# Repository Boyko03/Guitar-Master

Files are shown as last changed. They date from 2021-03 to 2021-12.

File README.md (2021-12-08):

# *Guitar Master*
Have you ever dreamed of learning to play the guitar? Guitar Master will help you make your dream come true!

Read this in other languages: [Bulgarian](https://github.com/Boyko03/Guitar-Master/blob/main/README.bg.md)
## How do I download and use the project?

### Necessary parts
[Parts](https://github.com/Boyko03/Guitar-Master/blob/main/Hardware/parts.csv)

### Download instructions

1) Clone the GitHub repository locally
```bash
  git clone https://github.com/Boyko03/Guitar-Master.git
```
Or download it as a [zip](https://github.com/Boyko03/Guitar-Master/archive/refs/heads/main.zip)

### Installation instructions

1) The Software/main directory contains the program that Arduino Uno runs.
2) Load the program into your Arduino

### Instructions for starting the project

1) It is recommended to solder the elements on the boards included in the repository, but the scheme can also be recreated on a Breadboard.
2) When the elements are connected correctly, a "snake" will appear on the fretboard, and a menu will be displayed on the LCD screen, which is controlled by the buttons.
3) Guitar Master can display notes and chords as well as songs.

## Technologies used

* [KiCad](https://kicad.org/) - A Cross Platform and Open Source Electronics Design Automation Suite
* [Arduino](https://www.arduino.cc/) - Arduino is an open source project for the design and production of an electronic platform with easy-to-use free hardware and software,

## Аbout the authors of the project

* **Boyko Georgiev** - *programmer, designer, hardware engineer* - [Boyko03](https://github.com/Boyko03)

## Photos and demonstration
[Electric Schema](https://github.com/Boyko03/Guitar-Master/blob/main/Hardware/guitar.pdf) <br />
[Demo](https://github.com/Boyko03/Guitar-Master/blob/main/Presentation/demo.mp4) <br />
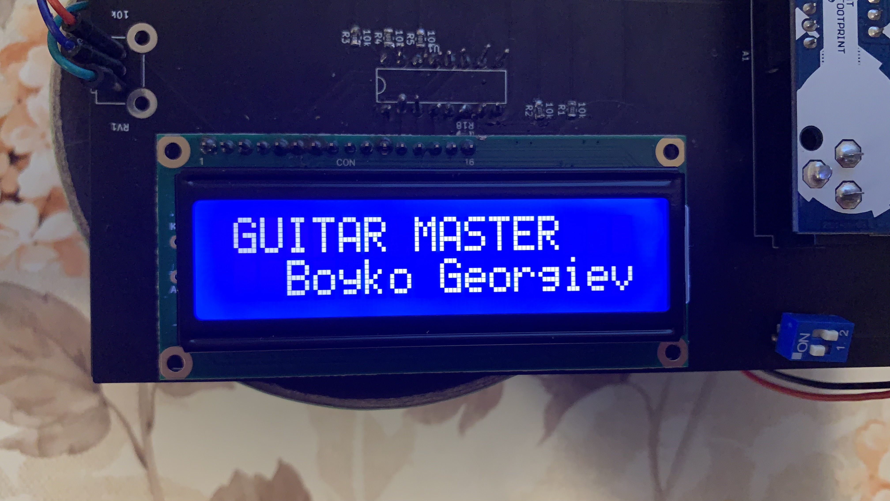
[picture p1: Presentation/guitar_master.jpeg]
Guitar Master

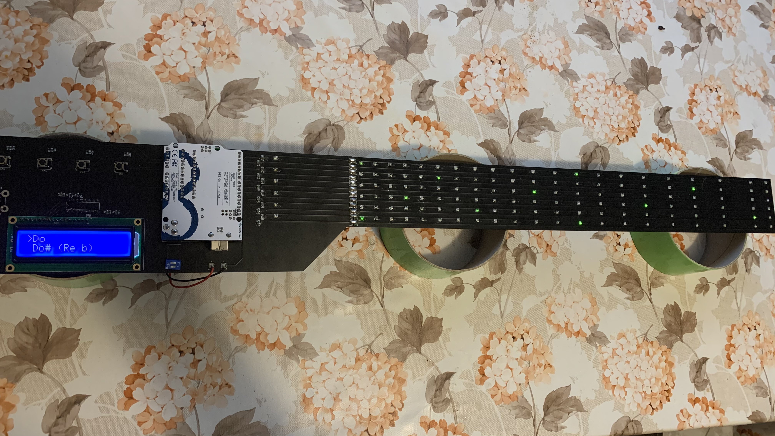
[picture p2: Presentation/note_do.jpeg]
Note Do

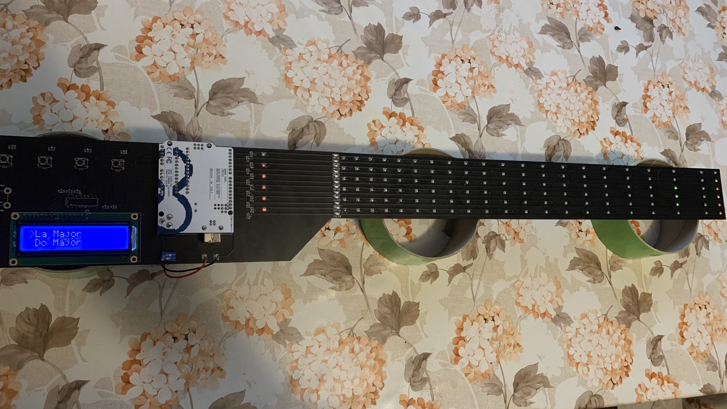
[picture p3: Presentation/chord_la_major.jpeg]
Chord La Major


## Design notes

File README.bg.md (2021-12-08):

# *Guitar Master*

Мечтали ли сте някога да се научите да свирите на китара? Guitar Master ще ви помогне да сбъднете мечтата си!

Read this in other languages: [English](https://github.com/Boyko03/Guitar-Master/blob/main/README.md)
## Как да си сваля и използвам проекта?

### Необходими материали
[Материали](https://github.com/Boyko03/Guitar-Master/blob/main/Hardware/parts.csv)

### Инструкции за сваляне

1) Клонирайте GitHub хранилището локално
```bash
  git clone https://github.com/Boyko03/Guitar-Master.git
```
Или го изтеглете като [zip](https://github.com/Boyko03/guitar_project/archive/refs/heads/main.zip)

### Инструкции за инсталация

1) В директория Software/main се намира програмата, която изпълнява Arduino Uno.
2) Заредете програмата във вашето Ардуино

### Инструкции за стартиране на проекта

1) Препоръчително е елементите да се запоят на платките, приложени в хранилището, но схемата може да се пресъздаде и на бредборд.
2) При правилно свързване на елементите, по грифа ще премине "змия", а на LCD екранчето ще се покаже меню, което се управлява с бутоните.
3) Guitar Master може да показва ноти и акорди, а също и песни.

## Използвани технологии

* [KiCad](https://kicad.org/) - програма за чертаене на електрически схеми и за проектиране на платки
* [Arduino](https://www.arduino.cc/) - Микроконтролер

## Информация за авторите на проекта

* **Бойко Георгиев** - *програмист, дизайнер, хардуерист* - [Boyko03](https://github.com/Boyko03)

## Снимки и демо
[Electric Schema](https://github.com/Boyko03/Guitar-Master/blob/main/Hardware/guitar.pdf) <br />
[Demo](https://github.com/Boyko03/Guitar-Master/blob/main/Presentation/demo.mp4) <br />
Guitar Master
Note Do
Chord La Major

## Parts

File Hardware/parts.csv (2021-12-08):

Item | Qty | Reference(s) | Value
1 | 1 | A1 | Arduino Uno R3
2 | 1 | BT1 | 9V Battery
3 | 120 | D[2-21, 24-43, 46-65, 68-87, 90-109, 112-130] | LED SMD 0603 Green
4 | 12 | D[1, 22-23, 44-45, 66-D67, 88-89, 110-111, 132] | LED SMD 0603 Red
5 | 1 | LCD1 | LCD 1602A
6 | 9 | R1-R5, R19-R22 | R10k SMD 0805
7 | 12 | R6-R17 | R220 SMD 0805
8 | 1 | R18 | R330 SMD 0805
9 | 1 | RV1 | Potentiometer 10k
10 | 1 | SW1 | Dip Switch 1
11 | 4 | SW2-SW5 | Switch Button
12 | 1 | U1 | PCF8574 TH Port Expander

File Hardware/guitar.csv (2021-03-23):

Source: | C:\Users\Dell Xps\Documents\guitar\guitar.sch
Date: | 3/15/2021 6:39:24 PM
Tool: | Eeschema (5.1.8)-1
Generator: | D:\KiCad\bin\scripting\plugins/bom_csv_grouped_by_value.py
Component Count: | 164
Individual Components:
Item | Qty | Reference(s) | Value | LibPart | Footprint | Datasheet
 |  | A1 | Arduino_UNO_R3 | MCU_Module:Arduino_UNO_R3 | Module:Arduino_UNO_R3 | https://www.arduino.cc/en/Main/arduinoBoardUno
 |  | BT1 | Battery | Device:Battery | Battery:BatteryHolder_Eagle_12BH611-GR | ~
 |  | D1 | 1-12 | Device:LED | LED_SMD:LED_0603_1608Metric | ~
 |  | D2 | 2-12 | Device:LED | LED_SMD:LED_0603_1608Metric | ~
 |  | D3 | 3-12 | Device:LED | LED_SMD:LED_0603_1608Metric | ~
 |  | D4 | 4-12 | Device:LED | LED_SMD:LED_0603_1608Metric | ~
 |  | D5 | 5-12 | Device:LED | LED_SMD:LED_0603_1608Metric | ~
 |  | D6 | 6-12 | Device:LED | LED_SMD:LED_0603_1608Metric | ~
 |  | D7 | 7-12 | Device:LED | LED_SMD:LED_0603_1608Metric | ~
 |  | D8 | 8-12 | Device:LED | LED_SMD:LED_0603_1608Metric | ~
 |  | D9 | 9-12 | Device:LED | LED_SMD:LED_0603_1608Metric | ~
 |  | D10 | 10-12 | Device:LED | LED_SMD:LED_0603_1608Metric | ~
 |  | D11 | 11-12 | Device:LED | LED_SMD:LED_0603_1608Metric | ~
 |  | D12 | 1-11 | Device:LED | LED_SMD:LED_0603_1608Metric | ~
 |  | D13 | 2-11 | Device:LED | LED_SMD:LED_0603_1608Metric | ~
 |  | D14 | 3-11 | Device:LED | LED_SMD:LED_0603_1608Metric | ~
 |  | D15 | 4-11 | Device:LED | LED_SMD:LED_0603_1608Metric | ~
 |  | D16 | 5-11 | Device:LED | LED_SMD:LED_0603_1608Metric | ~
 |  | D17 | 6-11 | Device:LED | LED_SMD:LED_0603_1608Metric | ~
 |  | D18 | 7-11 | Device:LED | LED_SMD:LED_0603_1608Metric | ~
 |  | D19 | 8-11 | Device:LED | LED_SMD:LED_0603_1608Metric | ~
 |  | D20 | 9-11 | Device:LED | LED_SMD:LED_0603_1608Metric | ~
 |  | D21 | 10-11 | Device:LED | LED_SMD:LED_0603_1608Metric | ~
 |  | D22 | 12-11 | Device:LED | LED_SMD:LED_0603_1608Metric | ~
 |  | D23 | 1-10 | Device:LED | LED_SMD:LED_0603_1608Metric | ~
 |  | D24 | 2-10 | Device:LED | LED_SMD:LED_0603_1608Metric | ~
 |  | D25 | 3-10 | Device:LED | LED_SMD:LED_0603_1608Metric | ~
 |  | D26 | 4-10 | Device:LED | LED_SMD:LED_0603_1608Metric | ~
 |  | D27 | 5-10 | Device:LED | LED_SMD:LED_0603_1608Metric | ~
 |  | D28 | 6-10 | Device:LED | LED_SMD:LED_0603_1608Metric | ~
 |  | D29 | 7-10 | Device:LED | LED_SMD:LED_0603_1608Metric | ~
 |  | D30 | 8-10 | Device:LED | LED_SMD:LED_0603_1608Metric | ~
 |  | D31 | 9-10 | Device:LED | LED_SMD:LED_0603_1608Metric | ~
 |  | D32 | 11-10 | Device:LED | LED_SMD:LED_0603_1608Metric | ~
 |  | D33 | 12-10 | Device:LED | LED_SMD:LED_0603_1608Metric | ~
 |  | D34 | 1-9 | Device:LED | LED_SMD:LED_0603_1608Metric | ~
 |  | D35 | 2-9 | Device:LED | LED_SMD:LED_0603_1608Metric | ~
 |  | D36 | 3-9 | Device:LED | LED_SMD:LED_0603_1608Metric | ~
 |  | D37 | 4-9 | Device:LED | LED_SMD:LED_0603_1608Metric | ~
 |  | D38 | 5-9 | Device:LED | LED_SMD:LED_0603_1608Metric | ~
 |  | D39 | 6-9 | Device:LED | LED_SMD:LED_0603_1608Metric | ~
 |  | D40 | 7-9 | Device:LED | LED_SMD:LED_0603_1608Metric | ~
 |  | D41 | 8-9 | Device:LED | LED_SMD:LED_0603_1608Metric | ~
 |  | D42 | 10-9 | Device:LED | LED_SMD:LED_0603_1608Metric | ~
 |  | D43 | 11-9 | Device:LED | LED_SMD:LED_0603_1608Metric | ~
 |  | D44 | 12-9 | Device:LED | LED_SMD:LED_0603_1608Metric | ~
 |  | D45 | 1-8 | Device:LED | LED_SMD:LED_0603_1608Metric | ~
 |  | D46 | 2-8 | Device:LED | LED_SMD:LED_0603_1608Metric | ~
 |  | D47 | 3-8 | Device:LED | LED_SMD:LED_0603_1608Metric | ~
 |  | D48 | 4-8 | Device:LED | LED_SMD:LED_0603_1608Metric | ~
 |  | D49 | 5-8 | Device:LED | LED_SMD:LED_0603_1608Metric | ~
 |  | D50 | 6-8 | Device:LED | LED_SMD:LED_0603_1608Metric | ~
 |  | D51 | 7-8 | Device:LED | LED_SMD:LED_0603_1608Metric | ~
 |  | D52 | 9-8 | Device:LED | LED_SMD:LED_0603_1608Metric | ~
 |  | D53 | 10-8 | Device:LED | LED_SMD:LED_0603_1608Metric | ~
 |  | D54 | 11-8 | Device:LED | LED_SMD:LED_0603_1608Metric | ~
 |  | D55 | 12-8 | Device:LED | LED_SMD:LED_0603_1608Metric | ~
 |  | D56 | 1-7 | Device:LED | LED_SMD:LED_0603_1608Metric | ~
 |  | D57 | 2-7 | Device:LED | LED_SMD:LED_0603_1608Metric | ~
 |  | D58 | 3-7 | Device:LED | LED_SMD:LED_0603_1608Metric | ~
 |  | D59 | 4-7 | Device:LED | LED_SMD:LED_0603_1608Metric | ~
 |  | D60 | 5-7 | Device:LED | LED_SMD:LED_0603_1608Metric | ~
 |  | D61 | 6-7 | Device:LED | LED_SMD:LED_0603_1608Metric | ~
 |  | D62 | 8-7 | Device:LED | LED_SMD:LED_0603_1608Metric | ~
 |  | D63 | 9-7 | Device:LED | LED_SMD:LED_0603_1608Metric | ~
 |  | D64 | 10-7 | Device:LED | LED_SMD:LED_0603_1608Metric | ~
 |  | D65 | 11-7 | Device:LED | LED_SMD:LED_0603_1608Metric | ~
 |  | D66 | 12-7 | Device:LED | LED_SMD:LED_0603_1608Metric | ~
 |  | D67 | 1-6 | Device:LED | LED_SMD:LED_0603_1608Metric | ~
 |  | D68 | 2-6 | Device:LED | LED_SMD:LED_0603_1608Metric | ~
 |  | D69 | 3-6 | Device:LED | LED_SMD:LED_0603_1608Metric | ~
 |  | D70 | 4-6 | Device:LED | LED_SMD:LED_0603_1608Metric | ~
 |  | D71 | 5-6 | Device:LED | LED_SMD:LED_0603_1608Metric | ~
 |  | D72 | 7-6 | Device:LED | LED_SMD:LED_0603_1608Metric | ~
 |  | D73 | 8-6 | Device:LED | LED_SMD:LED_0603_1608Metric | ~
 |  | D74 | 9-6 | Device:LED | LED_SMD:LED_0603_1608Metric | ~
 |  | D75 | 10-6 | Device:LED | LED_SMD:LED_0603_1608Metric | ~
 |  | D76 | 11-6 | Device:LED | LED_SMD:LED_0603_1608Metric | ~
 |  | D77 | 12-6 | Device:LED | LED_SMD:LED_0603_1608Metric | ~
 |  | D78 | 1-5 | Device:LED | LED_SMD:LED_0603_1608Metric | ~
 |  | D79 | 2-5 | Device:LED | LED_SMD:LED_0603_1608Metric | ~
 |  | D80 | 3-5 | Device:LED | LED_SMD:LED_0603_1608Metric | ~
 |  | D81 | 4-5 | Device:LED | LED_SMD:LED_0603_1608Metric | ~
 |  | D82 | 6-5 | Device:LED | LED_SMD:LED_0603_1608Metric | ~
 |  | D83 | 7-5 | Device:LED | LED_SMD:LED_0603_1608Metric | ~
 |  | D84 | 8-5 | Device:LED | LED_SMD:LED_0603_1608Metric | ~
 |  | D85 | 9-5 | Device:LED | LED_SMD:LED_0603_1608Metric | ~
 |  | D86 | 10-5 | Device:LED | LED_SMD:LED_0603_1608Metric | ~
 |  | D87 | 11-5 | Device:LED | LED_SMD:LED_0603_1608Metric | ~
 |  | D88 | 12-5 | Device:LED | LED_SMD:LED_0603_1608Metric | ~
 |  | D89 | 1-4 | Device:LED | LED_SMD:LED_0603_1608Metric | ~
 |  | D90 | 2-4 | Device:LED | LED_SMD:LED_0603_1608Metric | ~
 |  | D91 | 3-4 | Device:LED | LED_SMD:LED_0603_1608Metric | ~
 |  | D92 | 5-4 | Device:LED | LED_SMD:LED_0603_1608Metric | ~
 |  | D93 | 6-4 | Device:LED | LED_SMD:LED_0603_1608Metric | ~
 |  | D94 | 7-4 | Device:LED | LED_SMD:LED_0603_1608Metric | ~
 |  | D95 | 8-4 | Device:LED | LED_SMD:LED_0603_1608Metric | ~
 |  | D96 | 9-4 | Device:LED | LED_SMD:LED_0603_1608Metric | ~
 |  | D97 | 10-4 | Device:LED | LED_SMD:LED_0603_1608Metric | ~
 |  | D98 | 11-4 | Device:LED | LED_SMD:LED_0603_1608Metric | ~
 |  | D99 | 12-4 | Device:LED | LED_SMD:LED_0603_1608Metric | ~
 |  | D100 | 1-3 | Device:LED | LED_SMD:LED_0603_1608Metric | ~
 |  | D101 | 2-3 | Device:LED | LED_SMD:LED_0603_1608Metric | ~
 |  | D102 | 4-3 | Device:LED | LED_SMD:LED_0603_1608Metric | ~
 |  | D103 | 5-3 | Device:LED | LED_SMD:LED_0603_1608Metric | ~
 |  | D104 | 6-3 | Device:LED | LED_SMD:LED_0603_1608Metric | ~
 |  | D105 | 7-3 | Device:LED | LED_SMD:LED_0603_1608Metric | ~
 |  | D106 | 8-3 | Device:LED | LED_SMD:LED_0603_1608Metric | ~
 |  | D107 | 9-3 | Device:LED | LED_SMD:LED_0603_1608Metric | ~
 |  | D108 | 10-3 | Device:LED | LED_SMD:LED_0603_1608Metric | ~
 |  | D109 | 11-3 | Device:LED | LED_SMD:LED_0603_1608Metric | ~
 |  | D110 | 12-3 | Device:LED | LED_SMD:LED_0603_1608Metric | ~
 |  | D111 | 1-2 | Device:LED | LED_SMD:LED_0603_1608Metric | ~
 |  | D112 | 3-2 | Device:LED | LED_SMD:LED_0603_1608Metric | ~
 |  | D113 | 4-2 | Device:LED | LED_SMD:LED_0603_1608Metric | ~
 |  | D114 | 5-2 | Device:LED | LED_SMD:LED_0603_1608Metric | ~
 |  | D115 | 6-2 | Device:LED | LED_SMD:LED_0603_1608Metric | ~
 |  | D116 | 7-2 | Device:LED | LED_SMD:LED_0603_1608Metric | ~
 |  | D117 | 8-2 | Device:LED | LED_SMD:LED_0603_1608Metric | ~
 |  | D118 | 9-2 | Device:LED | LED_SMD:LED_0603_1608Metric | ~
 |  | D119 | 10-2 | Device:LED | LED_SMD:LED_0603_1608Metric | ~
 |  | D120 | 11-2 | Device:LED | LED_SMD:LED_0603_1608Metric | ~
 |  | D121 | 12-2 | Device:LED | LED_SMD:LED_0603_1608Metric | ~
 |  | D122 | 2-1 | Device:LED | LED_SMD:LED_0603_1608Metric | ~
 |  | D123 | 3-1 | Device:LED | LED_SMD:LED_0603_1608Metric | ~
 |  | D124 | 4-1 | Device:LED | LED_SMD:LED_0603_1608Metric | ~
 |  | D125 | 5-1 | Device:LED | LED_SMD:LED_0603_1608Metric | ~
 |  | D126 | 6-1 | Device:LED | LED_SMD:LED_0603_1608Metric | ~
 |  | D127 | 7-1 | Device:LED | LED_SMD:LED_0603_1608Metric | ~
 |  | D128 | 8-1 | Device:LED | LED_SMD:LED_0603_1608Metric | ~
 |  | D129 | 9-1 | Device:LED | LED_SMD:LED_0603_1608Metric | ~
 |  | D130 | 10-1 | Device:LED | LED_SMD:LED_0603_1608Metric | ~
 |  | D131 | 11-1 | Device:LED | LED_SMD:LED_0603_1608Metric | ~
 |  | D132 | 12-1 | Device:LED | LED_SMD:LED_0603_1608Metric | ~
 |  | LCD1 | 1602A | Display_Character:1602A | Display:1602A | http://hades.mech.northwestern.edu/images/f/f7/LCD16x2_HJ1602A.pdf
 |  | R1 | 10k | Device:R | Resistor_SMD:R_0805_2012Metric | ~
 |  | R2 | 10k | Device:R | Resistor_SMD:R_0805_2012Metric | ~
 |  | R3 | 10k | Device:R | Resistor_SMD:R_0805_2012Metric | ~
 |  | R4 | 10k | Device:R | Resistor_SMD:R_0805_2012Metric | ~
 |  | R5 | 10k | Device:R | Resistor_SMD:R_0805_2012Metric | ~
 |  | R6 | 220 | Device:R | Resistor_SMD:R_0805_2012Metric | ~
 |  | R7 | 220 | Device:R | Resistor_SMD:R_0805_2012Metric | ~
 |  | R8 | 220 | Device:R | Resistor_SMD:R_0805_2012Metric | ~
 |  | R9 | 220 | Device:R | Resistor_SMD:R_0805_2012Metric | ~
 |  | R10 | 220 | Device:R | Resistor_SMD:R_0805_2012Metric | ~
 |  | R11 | 220 | Device:R | Resistor_SMD:R_0805_2012Metric | ~
 |  | R12 | 220 | Device:R | Resistor_SMD:R_0805_2012Metric | ~
 |  | R13 | 220 | Device:R | Resistor_SMD:R_0805_2012Metric | ~
 |  | R14 | 220 | Device:R | Resistor_SMD:R_0805_2012Metric | ~
 |  | R15 | 220 | Device:R | Resistor_SMD:R_0805_2012Metric | ~
 |  | R16 | 220 | Device:R | Resistor_SMD:R_0805_2012Metric | ~
 |  | R17 | 220 | Device:R | Resistor_SMD:R_0805_2012Metric | ~
 |  | R18 | 330 | Device:R | Resistor_SMD:R_0805_2012Metric | ~
 |  | R19 | 10k | Device:R | Resistor_SMD:R_0805_2012Metric | ~
 |  | R20 | 10k | Device:R | Resistor_SMD:R_0805_2012Metric | ~
 |  | R21 | 10k | Device:R | Resistor_SMD:R_0805_2012Metric | ~
 |  | R22 | 10k | Device:R | Resistor_SMD:R_0805_2012Metric | ~
 |  | RV1 | 10k | Device:R_POT_Small | Potentiometer_THT:Potentiometer_Alps_RK09K_Single_Horizontal | ~
 |  | SW1 | SW_Push | Switch:SW_Push | Button_Switch_THT:SW_DIP_SPSTx01_Slide_6.7x4.1mm_W7.62mm_P2.54mm_LowProfile | ~
 |  | SW2 | SW_Push | Switch:SW_Push | Button_Switch_THT:SW_Tactile_Straight_KSA0Axx1LFTR | ~
 |  | SW3 | SW_Push | Switch:SW_Push | Button_Switch_THT:SW_Tactile_Straight_KSA0Axx1LFTR | ~
 |  | SW4 | SW_Push | Switch:SW_Push | Button_Switch_THT:SW_Tactile_Straight_KSA0Axx1LFTR | ~
 |  | SW5 | SW_Push | Switch:SW_Push | Button_Switch_THT:SW_Tactile_Straight_KSA0Axx1LFTR | ~
 |  | U1 | PCF8574 | Interface_Expansion:PCF8574 | Connector:PCF8574 | http://www.nxp.com/documents/data_sheet/PCF8574_PCF8574A.pdf
Collated Components:
Item | Qty | Reference(s) | Value | LibPart | Footprint | Datasheet
1 | 1 | A1 | Arduino_UNO_R3 | MCU_Module:Arduino_UNO_R3 | Module:Arduino_UNO_R3 | https://www.arduino.cc/en/Main/arduinoBoardUno
2 | 1 | BT1 | Battery | Device:Battery | Battery:BatteryHolder_Eagle_12BH611-GR | ~
3 | 1 | D1 | 1-12 | Device:LED | LED_SMD:LED_0603_1608Metric | ~
4 | 1 | D2 | 2-12 | Device:LED | LED_SMD:LED_0603_1608Metric | ~
5 | 1 | D3 | 3-12 | Device:LED | LED_SMD:LED_0603_1608Metric | ~
6 | 1 | D4 | 4-12 | Device:LED | LED_SMD:LED_0603_1608Metric | ~
7 | 1 | D5 | 5-12 | Device:LED | LED_SMD:LED_0603_1608Metric | ~
8 | 1 | D6 | 6-12 | Device:LED | LED_SMD:LED_0603_1608Metric | ~
9 | 1 | D7 | 7-12 | Device:LED | LED_SMD:LED_0603_1608Metric | ~
10 | 1 | D8 | 8-12 | Device:LED | LED_SMD:LED_0603_1608Metric | ~
11 | 1 | D9 | 9-12 | Device:LED | LED_SMD:LED_0603_1608Metric | ~
12 | 1 | D10 | 10-12 | Device:LED | LED_SMD:LED_0603_1608Metric | ~
13 | 1 | D11 | 11-12 | Device:LED | LED_SMD:LED_0603_1608Metric | ~
14 | 1 | D12 | 1-11 | Device:LED | LED_SMD:LED_0603_1608Metric | ~
15 | 1 | D13 | 2-11 | Device:LED | LED_SMD:LED_0603_1608Metric | ~
16 | 1 | D14 | 3-11 | Device:LED | LED_SMD:LED_0603_1608Metric | ~
17 | 1 | D15 | 4-11 | Device:LED | LED_SMD:LED_0603_1608Metric | ~
18 | 1 | D16 | 5-11 | Device:LED | LED_SMD:LED_0603_1608Metric | ~
19 | 1 | D17 | 6-11 | Device:LED | LED_SMD:LED_0603_1608Metric | ~
20 | 1 | D18 | 7-11 | Device:LED | LED_SMD:LED_0603_1608Metric | ~
21 | 1 | D19 | 8-11 | Device:LED | LED_SMD:LED_0603_1608Metric | ~
22 | 1 | D20 | 9-11 | Device:LED | LED_SMD:LED_0603_1608Metric | ~
23 | 1 | D21 | 10-11 | Device:LED | LED_SMD:LED_0603_1608Metric | ~
24 | 1 | D22 | 12-11 | Device:LED | LED_SMD:LED_0603_1608Metric | ~
25 | 1 | D23 | 1-10 | Device:LED | LED_SMD:LED_0603_1608Metric | ~
26 | 1 | D24 | 2-10 | Device:LED | LED_SMD:LED_0603_1608Metric | ~
27 | 1 | D25 | 3-10 | Device:LED | LED_SMD:LED_0603_1608Metric | ~
28 | 1 | D26 | 4-10 | Device:LED | LED_SMD:LED_0603_1608Metric | ~
29 | 1 | D27 | 5-10 | Device:LED | LED_SMD:LED_0603_1608Metric | ~
30 | 1 | D28 | 6-10 | Device:LED | LED_SMD:LED_0603_1608Metric | ~
31 | 1 | D29 | 7-10 | Device:LED | LED_SMD:LED_0603_1608Metric | ~
32 | 1 | D30 | 8-10 | Device:LED | LED_SMD:LED_0603_1608Metric | ~
33 | 1 | D31 | 9-10 | Device:LED | LED_SMD:LED_0603_1608Metric | ~
34 | 1 | D32 | 11-10 | Device:LED | LED_SMD:LED_0603_1608Metric | ~
35 | 1 | D33 | 12-10 | Device:LED | LED_SMD:LED_0603_1608Metric | ~
36 | 1 | D34 | 1-9 | Device:LED | LED_SMD:LED_0603_1608Metric | ~
37 | 1 | D35 | 2-9 | Device:LED | LED_SMD:LED_0603_1608Metric | ~
38 | 1 | D36 | 3-9 | Device:LED | LED_SMD:LED_0603_1608Metric | ~
39 | 1 | D37 | 4-9 | Device:LED | LED_SMD:LED_0603_1608Metric | ~
40 | 1 | D38 | 5-9 | Device:LED | LED_SMD:LED_0603_1608Metric | ~
41 | 1 | D39 | 6-9 | Device:LED | LED_SMD:LED_0603_1608Metric | ~
42 | 1 | D40 | 7-9 | Device:LED | LED_SMD:LED_0603_1608Metric | ~
43 | 1 | D41 | 8-9 | Device:LED | LED_SMD:LED_0603_1608Metric | ~
44 | 1 | D42 | 10-9 | Device:LED | LED_SMD:LED_0603_1608Metric | ~
45 | 1 | D43 | 11-9 | Device:LED | LED_SMD:LED_0603_1608Metric | ~
46 | 1 | D44 | 12-9 | Device:LED | LED_SMD:LED_0603_1608Metric | ~
47 | 1 | D45 | 1-8 | Device:LED | LED_SMD:LED_0603_1608Metric | ~
48 | 1 | D46 | 2-8 | Device:LED | LED_SMD:LED_0603_1608Metric | ~
49 | 1 | D47 | 3-8 | Device:LED | LED_SMD:LED_0603_1608Metric | ~
50 | 1 | D48 | 4-8 | Device:LED | LED_SMD:LED_0603_1608Metric | ~
51 | 1 | D49 | 5-8 | Device:LED | LED_SMD:LED_0603_1608Metric | ~
52 | 1 | D50 | 6-8 | Device:LED | LED_SMD:LED_0603_1608Metric | ~
53 | 1 | D51 | 7-8 | Device:LED | LED_SMD:LED_0603_1608Metric | ~
54 | 1 | D52 | 9-8 | Device:LED | LED_SMD:LED_0603_1608Metric | ~
55 | 1 | D53 | 10-8 | Device:LED | LED_SMD:LED_0603_1608Metric | ~
56 | 1 | D54 | 11-8 | Device:LED | LED_SMD:LED_0603_1608Metric | ~
57 | 1 | D55 | 12-8 | Device:LED | LED_SMD:LED_0603_1608Metric | ~
58 | 1 | D56 | 1-7 | Device:LED | LED_SMD:LED_0603_1608Metric | ~
59 | 1 | D57 | 2-7 | Device:LED | LED_SMD:LED_0603_1608Metric | ~
60 | 1 | D58 | 3-7 | Device:LED | LED_SMD:LED_0603_1608Metric | ~
61 | 1 | D59 | 4-7 | Device:LED | LED_SMD:LED_0603_1608Metric | ~
62 | 1 | D60 | 5-7 | Device:LED | LED_SMD:LED_0603_1608Metric | ~
63 | 1 | D61 | 6-7 | Device:LED | LED_SMD:LED_0603_1608Metric | ~
64 | 1 | D62 | 8-7 | Device:LED | LED_SMD:LED_0603_1608Metric | ~
65 | 1 | D63 | 9-7 | Device:LED | LED_SMD:LED_0603_1608Metric | ~
66 | 1 | D64 | 10-7 | Device:LED | LED_SMD:LED_0603_1608Metric | ~
67 | 1 | D65 | 11-7 | Device:LED | LED_SMD:LED_0603_1608Metric | ~
68 | 1 | D66 | 12-7 | Device:LED | LED_SMD:LED_0603_1608Metric | ~
69 | 1 | D67 | 1-6 | Device:LED | LED_SMD:LED_0603_1608Metric | ~
70 | 1 | D68 | 2-6 | Device:LED | LED_SMD:LED_0603_1608Metric | ~
71 | 1 | D69 | 3-6 | Device:LED | LED_SMD:LED_0603_1608Metric | ~
72 | 1 | D70 | 4-6 | Device:LED | LED_SMD:LED_0603_1608Metric | ~
73 | 1 | D71 | 5-6 | Device:LED | LED_SMD:LED_0603_1608Metric | ~
74 | 1 | D72 | 7-6 | Device:LED | LED_SMD:LED_0603_1608Metric | ~
75 | 1 | D73 | 8-6 | Device:LED | LED_SMD:LED_0603_1608Metric | ~
76 | 1 | D74 | 9-6 | Device:LED | LED_SMD:LED_0603_1608Metric | ~
77 | 1 | D75 | 10-6 | Device:LED | LED_SMD:LED_0603_1608Metric | ~
78 | 1 | D76 | 11-6 | Device:LED | LED_SMD:LED_0603_1608Metric | ~
79 | 1 | D77 | 12-6 | Device:LED | LED_SMD:LED_0603_1608Metric | ~
80 | 1 | D78 | 1-5 | Device:LED | LED_SMD:LED_0603_1608Metric | ~
81 | 1 | D79 | 2-5 | Device:LED | LED_SMD:LED_0603_1608Metric | ~
82 | 1 | D80 | 3-5 | Device:LED | LED_SMD:LED_0603_1608Metric | ~
83 | 1 | D81 | 4-5 | Device:LED | LED_SMD:LED_0603_1608Metric | ~
84 | 1 | D82 | 6-5 | Device:LED | LED_SMD:LED_0603_1608Metric | ~
85 | 1 | D83 | 7-5 | Device:LED | LED_SMD:LED_0603_1608Metric | ~
86 | 1 | D84 | 8-5 | Device:LED | LED_SMD:LED_0603_1608Metric | ~
87 | 1 | D85 | 9-5 | Device:LED | LED_SMD:LED_0603_1608Metric | ~
88 | 1 | D86 | 10-5 | Device:LED | LED_SMD:LED_0603_1608Metric | ~
89 | 1 | D87 | 11-5 | Device:LED | LED_SMD:LED_0603_1608Metric | ~
90 | 1 | D88 | 12-5 | Device:LED | LED_SMD:LED_0603_1608Metric | ~
91 | 1 | D89 | 1-4 | Device:LED | LED_SMD:LED_0603_1608Metric | ~
92 | 1 | D90 | 2-4 | Device:LED | LED_SMD:LED_0603_1608Metric | ~
93 | 1 | D91 | 3-4 | Device:LED | LED_SMD:LED_0603_1608Metric | ~
94 | 1 | D92 | 5-4 | Device:LED | LED_SMD:LED_0603_1608Metric | ~
95 | 1 | D93 | 6-4 | Device:LED | LED_SMD:LED_0603_1608Metric | ~
96 | 1 | D94 | 7-4 | Device:LED | LED_SMD:LED_0603_1608Metric | ~
97 | 1 | D95 | 8-4 | Device:LED | LED_SMD:LED_0603_1608Metric | ~
98 | 1 | D96 | 9-4 | Device:LED | LED_SMD:LED_0603_1608Metric | ~
99 | 1 | D97 | 10-4 | Device:LED | LED_SMD:LED_0603_1608Metric | ~
100 | 1 | D98 | 11-4 | Device:LED | LED_SMD:LED_0603_1608Metric | ~
101 | 1 | D99 | 12-4 | Device:LED | LED_SMD:LED_0603_1608Metric | ~
102 | 1 | D100 | 1-3 | Device:LED | LED_SMD:LED_0603_1608Metric | ~
103 | 1 | D101 | 2-3 | Device:LED | LED_SMD:LED_0603_1608Metric | ~
104 | 1 | D102 | 4-3 | Device:LED | LED_SMD:LED_0603_1608Metric | ~
105 | 1 | D103 | 5-3 | Device:LED | LED_SMD:LED_0603_1608Metric | ~
106 | 1 | D104 | 6-3 | Device:LED | LED_SMD:LED_0603_1608Metric | ~
107 | 1 | D105 | 7-3 | Device:LED | LED_SMD:LED_0603_1608Metric | ~
108 | 1 | D106 | 8-3 | Device:LED | LED_SMD:LED_0603_1608Metric | ~
109 | 1 | D107 | 9-3 | Device:LED | LED_SMD:LED_0603_1608Metric | ~
110 | 1 | D108 | 10-3 | Device:LED | LED_SMD:LED_0603_1608Metric | ~
111 | 1 | D109 | 11-3 | Device:LED | LED_SMD:LED_0603_1608Metric | ~
112 | 1 | D110 | 12-3 | Device:LED | LED_SMD:LED_0603_1608Metric | ~
113 | 1 | D111 | 1-2 | Device:LED | LED_SMD:LED_0603_1608Metric | ~
114 | 1 | D112 | 3-2 | Device:LED | LED_SMD:LED_0603_1608Metric | ~
115 | 1 | D113 | 4-2 | Device:LED | LED_SMD:LED_0603_1608Metric | ~
116 | 1 | D114 | 5-2 | Device:LED | LED_SMD:LED_0603_1608Metric | ~
117 | 1 | D115 | 6-2 | Device:LED | LED_SMD:LED_0603_1608Metric | ~
118 | 1 | D116 | 7-2 | Device:LED | LED_SMD:LED_0603_1608Metric | ~
119 | 1 | D117 | 8-2 | Device:LED | LED_SMD:LED_0603_1608Metric | ~
120 | 1 | D118 | 9-2 | Device:LED | LED_SMD:LED_0603_1608Metric | ~
121 | 1 | D119 | 10-2 | Device:LED | LED_SMD:LED_0603_1608Metric | ~
122 | 1 | D120 | 11-2 | Device:LED | LED_SMD:LED_0603_1608Metric | ~
123 | 1 | D121 | 12-2 | Device:LED | LED_SMD:LED_0603_1608Metric | ~
124 | 1 | D122 | 2-1 | Device:LED | LED_SMD:LED_0603_1608Metric | ~
125 | 1 | D123 | 3-1 | Device:LED | LED_SMD:LED_0603_1608Metric | ~
126 | 1 | D124 | 4-1 | Device:LED | LED_SMD:LED_0603_1608Metric | ~
127 | 1 | D125 | 5-1 | Device:LED | LED_SMD:LED_0603_1608Metric | ~
128 | 1 | D126 | 6-1 | Device:LED | LED_SMD:LED_0603_1608Metric | ~
129 | 1 | D127 | 7-1 | Device:LED | LED_SMD:LED_0603_1608Metric | ~
130 | 1 | D128 | 8-1 | Device:LED | LED_SMD:LED_0603_1608Metric | ~
131 | 1 | D129 | 9-1 | Device:LED | LED_SMD:LED_0603_1608Metric | ~
132 | 1 | D130 | 10-1 | Device:LED | LED_SMD:LED_0603_1608Metric | ~
133 | 1 | D131 | 11-1 | Device:LED | LED_SMD:LED_0603_1608Metric | ~
134 | 1 | D132 | 12-1 | Device:LED | LED_SMD:LED_0603_1608Metric | ~
135 | 1 | LCD1 | 1602A | Display_Character:1602A | Display:1602A | http://hades.mech.northwestern.edu/images/f/f7/LCD16x2_HJ1602A.pdf
136 | 9 | R1, R2, R3, R4, R5, R19, R20, R21, R22 | 10k | Device:R | Resistor_SMD:R_0805_2012Metric | ~
137 | 12 | R6, R7, R8, R9, R10, R11, R12, R13, R14, R15, R16, R17 | 220 | Device:R | Resistor_SMD:R_0805_2012Metric | ~
138 | 1 | R18 | 330 | Device:R | Resistor_SMD:R_0805_2012Metric | ~
139 | 1 | RV1 | 10k | Device:R_POT_Small | Potentiometer_THT:Potentiometer_Alps_RK09K_Single_Horizontal | ~
140 | 1 | SW1 | SW_Push | Switch:SW_Push | Button_Switch_THT:SW_DIP_SPSTx01_Slide_6.7x4.1mm_W7.62mm_P2.54mm_LowProfile | ~
141 | 4 | SW2, SW3, SW4, SW5 | SW_Push | Switch:SW_Push | Button_Switch_THT:SW_Tactile_Straight_KSA0Axx1LFTR | ~
142 | 1 | U1 | PCF8574 | Interface_Expansion:PCF8574 | Connector:PCF8574 | http://www.nxp.com/documents/data_sheet/PCF8574_PCF8574A.pdf

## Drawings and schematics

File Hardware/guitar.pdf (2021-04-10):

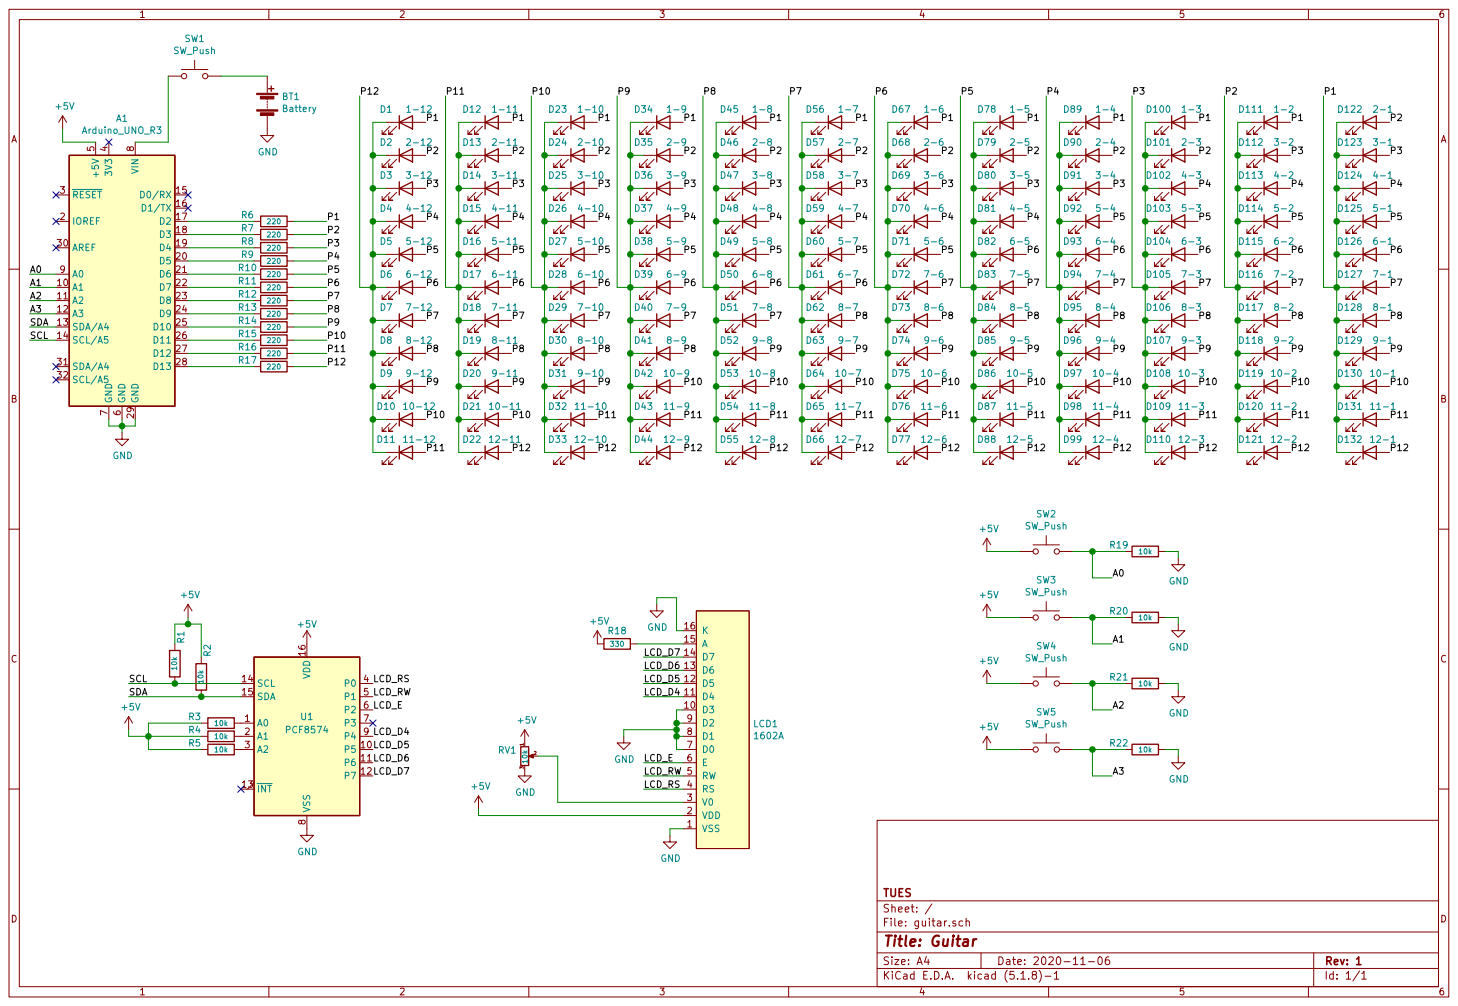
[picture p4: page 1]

File: guitar.sch Sheet: / TUES

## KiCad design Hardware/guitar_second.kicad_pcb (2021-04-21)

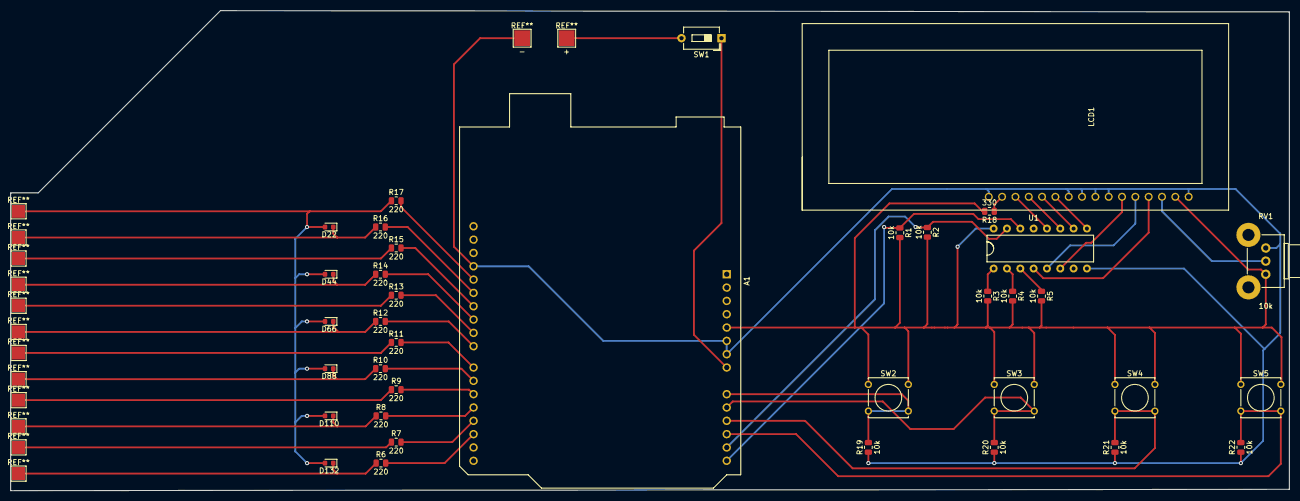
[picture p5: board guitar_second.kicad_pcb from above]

Board: 2 copper layers, 243.8 x 91.5 mm, 37 parts (0 on the bottom side), 40 nets.

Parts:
A1: Arduino_UNO_R3
D22: 12-11; LED_0603_1608Metric
D44: 12-9; LED_0603_1608Metric
D66: 12-7; LED_0603_1608Metric
D88: 12-5; LED_0603_1608Metric
D110: 12-3; LED_0603_1608Metric
D132: 12-1; LED_0603_1608Metric
LCD1: 1602A
R1, R2, R3, R4, R5, R19, R20, R21, R22: 10k; R_0805_2012Metric
R6, R7, R8, R9, R10, R11, R12, R13, R14, R15, R16, R17: 220; R_0805_2012Metric
R18: 330; R_0805_2012Metric
RV1: 10k; Potentiometer_Alps_RK09K_Single_Horizontal
SW1: SW_Push; SW_DIP_SPSTx01_Slide_6.7x4.1mm_W7.62mm_P2.54mm_LowProfile
SW2, SW3, SW4, SW5: SW_Push; SW_Tactile_Straight_KSA0Axx1LFTR
U1: PCF8574

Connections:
+5V: A1.5, LCD1.2, R1.2, R2.2, R3.2, R4.2, R5.2, R18.2, RV1.1, SW2.1, SW3.1, SW4.1, SW5.1, U1.16
/A0: A1.9, R19.2, SW2.2
/A1: A1.10, R20.2, SW3.2
/A2: A1.11, R21.2, SW4.2
/A3: A1.12, R22.2, SW5.2
/LCD_D4: LCD1.11, U1.9
/LCD_D5: LCD1.12, U1.10
/LCD_D6: LCD1.13, U1.11
/LCD_D7: LCD1.14, U1.12
/LCD_E: LCD1.6, U1.6
/LCD_RS: LCD1.4, U1.4
/LCD_RW: LCD1.5, U1.5
/P1: D132.1, R6.1
/P3: D110.1, R8.1
/P5: D88.1, R10.1
/P7: D66.1, R12.1
/P9: D44.1, R14.1
/P11: D22.1, R16.1
/P12: D22.2, D44.2, D66.2, D88.2, D110.2, D132.2, R17.1
/SCL: A1.14, R1.1, U1.14
/SDA: A1.13, R2.1, U1.15
GND: A1.6, A1.7, A1.29, LCD1.1, LCD1.7, LCD1.8, LCD1.9, LCD1.10, LCD1.16, R19.1, R20.1, R21.1, R22.1, RV1.3, U1.8
unnamed: A1.8, SW1.1
unnamed: A1.17, R6.2
unnamed: A1.18, R7.2
unnamed: A1.19, R8.2
unnamed: A1.20, R9.2
unnamed: A1.21, R10.2
unnamed: A1.22, R11.2
unnamed: A1.23, R12.2
unnamed: A1.24, R13.2
unnamed: A1.25, R14.2
unnamed: A1.26, R15.2
unnamed: A1.27, R16.2
unnamed: A1.28, R17.2
unnamed: LCD1.3, RV1.2
unnamed: LCD1.15, R18.1
unnamed: R3.1, U1.1
unnamed: R4.1, U1.2
unnamed: R5.1, U1.3

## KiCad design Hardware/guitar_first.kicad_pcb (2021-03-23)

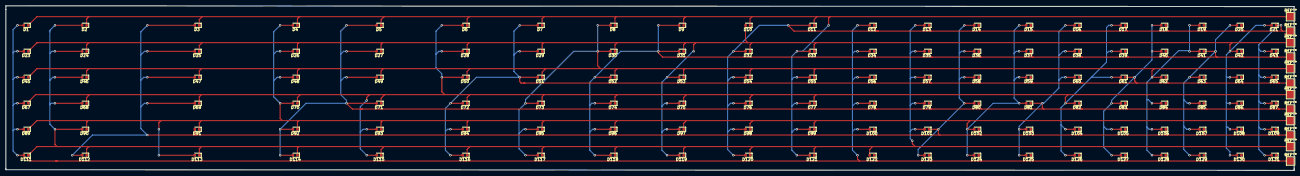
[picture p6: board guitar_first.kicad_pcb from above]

Board: 2 copper layers, 446.2 x 57.0 mm, 126 parts (0 on the bottom side), 12 nets.

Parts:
D1: 1-12; LED_0603_1608Metric
D2: 2-12; LED_0603_1608Metric
D3: 3-12; LED_0603_1608Metric
D4: 4-12; LED_0603_1608Metric
D5: 5-12; LED_0603_1608Metric
D6: 6-12; LED_0603_1608Metric
D7: 7-12; LED_0603_1608Metric
D8: 8-12; LED_0603_1608Metric
D9: 9-12; LED_0603_1608Metric
D10: 10-12; LED_0603_1608Metric
D11: 11-12; LED_0603_1608Metric
D12: 1-11; LED_0603_1608Metric
D13: 2-11; LED_0603_1608Metric
D14: 3-11; LED_0603_1608Metric
D15: 4-11; LED_0603_1608Metric
D16: 5-11; LED_0603_1608Metric
D17: 6-11; LED_0603_1608Metric
D18: 7-11; LED_0603_1608Metric
D19: 8-11; LED_0603_1608Metric
D20: 9-11; LED_0603_1608Metric
D21: 10-11; LED_0603_1608Metric
D23: 1-10; LED_0603_1608Metric
D24: 2-10; LED_0603_1608Metric
D25: 3-10; LED_0603_1608Metric
D26: 4-10; LED_0603_1608Metric
D27: 5-10; LED_0603_1608Metric
D28: 6-10; LED_0603_1608Metric
D29: 7-10; LED_0603_1608Metric
D30: 8-10; LED_0603_1608Metric
D31: 9-10; LED_0603_1608Metric
D32: 11-10; LED_0603_1608Metric
D33: 12-10; LED_0603_1608Metric
D34: 1-9; LED_0603_1608Metric
D35: 2-9; LED_0603_1608Metric
D36: 3-9; LED_0603_1608Metric
D37: 4-9; LED_0603_1608Metric
D38: 5-9; LED_0603_1608Metric
D39: 6-9; LED_0603_1608Metric
D40: 7-9; LED_0603_1608Metric
D41: 8-9; LED_0603_1608Metric
D42: 10-9; LED_0603_1608Metric
D43: 11-9; LED_0603_1608Metric
D45: 1-8; LED_0603_1608Metric
D46: 2-8; LED_0603_1608Metric
D47: 3-8; LED_0603_1608Metric
D48: 4-8; LED_0603_1608Metric
D49: 5-8; LED_0603_1608Metric
D50: 6-8; LED_0603_1608Metric
D51: 7-8; LED_0603_1608Metric
D52: 9-8; LED_0603_1608Metric
D53: 10-8; LED_0603_1608Metric
D54: 11-8; LED_0603_1608Metric
D55: 12-8; LED_0603_1608Metric
D56: 1-7; LED_0603_1608Metric
D57: 2-7; LED_0603_1608Metric
D58: 3-7; LED_0603_1608Metric
D59: 4-7; LED_0603_1608Metric
D60: 5-7; LED_0603_1608Metric
D61: 6-7; LED_0603_1608Metric
D62: 8-7; LED_0603_1608Metric
D63: 9-7; LED_0603_1608Metric
D64: 10-7; LED_0603_1608Metric
D65: 11-7; LED_0603_1608Metric
D67: 1-6; LED_0603_1608Metric
D68: 2-6; LED_0603_1608Metric
D69: 3-6; LED_0603_1608Metric
D70: 4-6; LED_0603_1608Metric
D71: 5-6; LED_0603_1608Metric
D72: 7-6; LED_0603_1608Metric
D73: 8-6; LED_0603_1608Metric
D74: 9-6; LED_0603_1608Metric
D75: 10-6; LED_0603_1608Metric
D76: 11-6; LED_0603_1608Metric
D77: 12-6; LED_0603_1608Metric
D78: 1-5; LED_0603_1608Metric
D79: 2-5; LED_0603_1608Metric
D80: 3-5; LED_0603_1608Metric
D81: 4-5; LED_0603_1608Metric
D82: 6-5; LED_0603_1608Metric
D83: 7-5; LED_0603_1608Metric
D84: 8-5; LED_0603_1608Metric
D85: 9-5; LED_0603_1608Metric
D86: 10-5; LED_0603_1608Metric
D87: 11-5; LED_0603_1608Metric
D89: 1-4; LED_0603_1608Metric
D90: 2-4; LED_0603_1608Metric
D91: 3-4; LED_0603_1608Metric
D92: 5-4; LED_0603_1608Metric
D93: 6-4; LED_0603_1608Metric
D94: 7-4; LED_0603_1608Metric
D95: 8-4; LED_0603_1608Metric
D96: 9-4; LED_0603_1608Metric
D97: 10-4; LED_0603_1608Metric
D98: 11-4; LED_0603_1608Metric
D99: 12-4; LED_0603_1608Metric
D100: 1-3; LED_0603_1608Metric
D101: 2-3; LED_0603_1608Metric
D102: 4-3; LED_0603_1608Metric
D103: 5-3; LED_0603_1608Metric
D104: 6-3; LED_0603_1608Metric
D105: 7-3; LED_0603_1608Metric
D106: 8-3; LED_0603_1608Metric
D107: 9-3; LED_0603_1608Metric
D108: 10-3; LED_0603_1608Metric
D109: 11-3; LED_0603_1608Metric
D111: 1-2; LED_0603_1608Metric
D112: 3-2; LED_0603_1608Metric
D113: 4-2; LED_0603_1608Metric
D114: 5-2; LED_0603_1608Metric
D115: 6-2; LED_0603_1608Metric
D116: 7-2; LED_0603_1608Metric
D117: 8-2; LED_0603_1608Metric
D118: 9-2; LED_0603_1608Metric
D119: 10-2; LED_0603_1608Metric
D120: 11-2; LED_0603_1608Metric
D121: 12-2; LED_0603_1608Metric
D122: 2-1; LED_0603_1608Metric
D123: 3-1; LED_0603_1608Metric
D124: 4-1; LED_0603_1608Metric
D125: 5-1; LED_0603_1608Metric
D126: 6-1; LED_0603_1608Metric
D127: 7-1; LED_0603_1608Metric
D128: 8-1; LED_0603_1608Metric
D129: 9-1; LED_0603_1608Metric
D130: 10-1; LED_0603_1608Metric
D131: 11-1; LED_0603_1608Metric

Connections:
/P1: D1.2, D12.2, D23.2, D34.2, D45.2, D56.2, D67.2, D78.2, D89.2, D100.2, D111.2, D122.1, D123.1, D124.1, D125.1, D126.1, D127.1, D128.1, D129.1, D130.1, D131.1
/P2: D2.2, D13.2, D24.2, D35.2, D46.2, D57.2, D68.2, D79.2, D90.2, D101.2, D111.1, D112.1, D113.1, D114.1, D115.1, D116.1, D117.1, D118.1, D119.1, D120.1, D121.1, D122.2
/P3: D3.2, D14.2, D25.2, D36.2, D47.2, D58.2, D69.2, D80.2, D91.2, D100.1, D101.1, D102.1, D103.1, D104.1, D105.1, D106.1, D107.1, D108.1, D109.1, D112.2, D123.2
/P4: D4.2, D15.2, D26.2, D37.2, D48.2, D59.2, D70.2, D81.2, D89.1, D90.1, D91.1, D92.1, D93.1, D94.1, D95.1, D96.1, D97.1, D98.1, D99.1, D102.2, D113.2, D124.2
/P5: D5.2, D16.2, D27.2, D38.2, D49.2, D60.2, D71.2, D78.1, D79.1, D80.1, D81.1, D82.1, D83.1, D84.1, D85.1, D86.1, D87.1, D92.2, D103.2, D114.2, D125.2
/P6: D6.2, D17.2, D28.2, D39.2, D50.2, D61.2, D67.1, D68.1, D69.1, D70.1, D71.1, D72.1, D73.1, D74.1, D75.1, D76.1, D77.1, D82.2, D93.2, D104.2, D115.2, D126.2
/P7: D7.2, D18.2, D29.2, D40.2, D51.2, D56.1, D57.1, D58.1, D59.1, D60.1, D61.1, D62.1, D63.1, D64.1, D65.1, D72.2, D83.2, D94.2, D105.2, D116.2, D127.2
/P8: D8.2, D19.2, D30.2, D41.2, D45.1, D46.1, D47.1, D48.1, D49.1, D50.1, D51.1, D52.1, D53.1, D54.1, D55.1, D62.2, D73.2, D84.2, D95.2, D106.2, D117.2, D128.2
/P9: D9.2, D20.2, D31.2, D34.1, D35.1, D36.1, D37.1, D38.1, D39.1, D40.1, D41.1, D42.1, D43.1, D52.2, D63.2, D74.2, D85.2, D96.2, D107.2, D118.2, D129.2
/P10: D10.2, D21.2, D23.1, D24.1, D25.1, D26.1, D27.1, D28.1, D29.1, D30.1, D31.1, D32.1, D33.1, D42.2, D53.2, D64.2, D75.2, D86.2, D97.2, D108.2, D119.2, D130.2
/P11: D11.2, D12.1, D13.1, D14.1, D15.1, D16.1, D17.1, D18.1, D19.1, D20.1, D21.1, D32.2, D43.2, D54.2, D65.2, D76.2, D87.2, D98.2, D109.2, D120.2, D131.2
/P12: D1.1, D2.1, D3.1, D4.1, D5.1, D6.1, D7.1, D8.1, D9.1, D10.1, D11.1, D33.2, D55.2, D77.2, D99.2, D121.2

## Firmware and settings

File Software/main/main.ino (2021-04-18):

#include <Wire.h>                  // Include Wire library (required for I2C devices)
#include <LiquidCrystal_I2C.h>     // Include LiquidCrystal_I2C library 

#define p1 2
#define p2 3
#define p3 4
#define p4 5
#define p5 6
#define p6 7
#define p7 8
#define p8 9
#define p9 10
#define p10 11
#define p11 12
#define p12 13

#define BTN_UP A0
#define BTN_DOWN A1
#define BTN_SELECT A2
#define BTN_BACK A3

#define MAIN_MENU_COUNT 4
#define NOTES_COUNT 12
#define CHORDS_COUNT 11

#define SNAKE_LENGTH 9

LiquidCrystal_I2C lcd(0x27, 16, 2);  // Configure LiquidCrystal_I2C library with 0x27 address, 16 columns and 2 rows

uint8_t btn_up = 0, btn_down = 0, btn_select = 0, btn_back = 0;
uint8_t main_menu = 1, sub_menu = 0;

void setup() {
  // put your setup code here, to run once:
  pinMode(BTN_UP, INPUT);
  pinMode(BTN_DOWN, INPUT);
  pinMode(BTN_SELECT, INPUT);
  pinMode(BTN_BACK, INPUT);

  lcd.init();                        // Initialize I2C LCD module
 
  lcd.backlight();                   // Turn backlight ON
 
  lcd.setCursor(0, 0);               // Go to column 0, row 0
  lcd.print("GUITAR MASTER");
  lcd.setCursor(0, 1);               // Go to column 0, row 1
  lcd.print("  Boyko Georgiev");

  show_demo();

  delay(500);

  show_menu();

  while(true) {
    on_up();
    on_down();
    on_select();
    on_back();
  
    show_action();
    init_leds();
  }
}

void on_up() {
  if(digitalRead(BTN_UP) == HIGH && btn_up == LOW){
    btn_up = HIGH;
    btn_down = LOW;
    btn_select = LOW;
    btn_back = LOW;

    if (sub_menu == 0) {
      main_menu--;
      if (main_menu < 1) {
        main_menu = MAIN_MENU_COUNT;
      }
    } else {
      switch(main_menu) {
        case 1: // notes
          sub_menu--;
          if (sub_menu < 1) {
            sub_menu = NOTES_COUNT;
          }
          break;
        case 2: // chords
          sub_menu--;
          if (sub_menu < 1) {
            sub_menu = CHORDS_COUNT;
          }
          break;
        case 3: break;
        case 4: break;
      }
    }

  } else if (digitalRead(BTN_UP) == LOW && btn_up == HIGH) {
    btn_up = LOW;

    show_menu();
  }
}

void on_down() {
  if(digitalRead(BTN_DOWN) == HIGH && btn_down == LOW){
    btn_up = LOW;
    btn_down = HIGH;
    btn_select = LOW;
    btn_back = LOW;

    if (sub_menu == 0) {
      main_menu++;
      if (main_menu > MAIN_MENU_COUNT) {
        main_menu = 1;
      }
    } else {
      switch(main_menu) {
        case 1: // notes
          sub_menu++;
          if (sub_menu > NOTES_COUNT) {
            sub_menu = 1;
          }
          break;
        case 2: // chords
          sub_menu++;
          if (sub_menu > CHORDS_COUNT) {
            sub_menu = 1;
          }
          break;
        case 3: break;
        case 4: break;
      }
    }
  
  } else if (digitalRead(BTN_DOWN) == LOW && btn_down == HIGH) {
    btn_down = LOW;

    show_menu();
  }
}

void on_select() {
  if(digitalRead(BTN_SELECT) == HIGH && btn_select == LOW){
    btn_up = LOW;
    btn_down = LOW;
    btn_select = HIGH;
    btn_back = LOW;

    if ((main_menu == 1 || main_menu == 2) && sub_menu == 0) {
      sub_menu = 1;
    } else if (main_menu == 3) {
      show_songs();
    } else if (main_menu == 4) {
      lcd.clear();
      lcd.print("    ::DEMO::");
      show_demo();
    }

  } else if (digitalRead(BTN_SELECT) == LOW && btn_select == HIGH) {
    btn_select = LOW;

    show_menu();
  }
}

void on_back() {
  if(digitalRead(BTN_BACK) == HIGH && btn_back == LOW){
    btn_up = LOW;
    btn_down = LOW;
    btn_select = LOW;
    btn_back = HIGH;

    if (sub_menu == 0) {
      main_menu--;
      if (main_menu < 1) {
        main_menu = MAIN_MENU_COUNT;
      }
    } else {
      sub_menu = 0;
    }

  } else if (digitalRead(BTN_BACK) == LOW && btn_back == HIGH) {
    btn_back = LOW;

    show_menu();
  }
}

void show_menu() {
  lcd.clear();

  switch(main_menu) {
    case 1: // notes
      switch(sub_menu) {
        case 0:
          lcd.print(">Notes");
          lcd.setCursor(0, 1);
          lcd.print(" Chords");
          break;
        case 1:
          lcd.print(">Do");
          lcd.setCursor(0, 1);
          lcd.print(" Do# (Re b)");
          break;
        case 2:
          lcd.print(">Do# (Re b)");
          lcd.setCursor(0, 1);
          lcd.print(" Re");
          break;
        case 3:
          lcd.print(">Re");
          lcd.setCursor(0, 1);
          lcd.print(" Re# (Mi b)");
          break;
        case 4:
          lcd.print(">Re# (Mi b)");
          lcd.setCursor(0, 1);
          lcd.print(" Mi");
          break;
        case 5:
          lcd.print(">Mi");
          lcd.setCursor(0, 1);
          lcd.print(" Fa");
          break;
        case 6:
          lcd.print(">Fa");
          lcd.setCursor(0, 1);
          lcd.print(" Fa# (Sol b)");
          break;
        case 7:
          lcd.print(">Fa# (Sol b)");
          lcd.setCursor(0, 1);
          lcd.print(" Sol");
          break;
        case 8:
          lcd.print(">Sol");
          lcd.setCursor(0, 1);
          lcd.print(" Sol# (La b)");
          break;
        case 9:
          lcd.print(">Sol# (La b)");
          lcd.setCursor(0, 1);
          lcd.print(" La");
          break;
        case 10:
          lcd.print(">La");
          lcd.setCursor(0, 1);
          lcd.print(" La# (Si b)");
          break;
        case 11:
          lcd.print(">La# (Si b)");
          lcd.setCursor(0, 1);
          lcd.print(" Si");
          break;
        case 12:
          lcd.print(" La# (Si b)");
          lcd.setCursor(0, 1);
          lcd.print(">Si");
          break;
      }
      break;
    case 2:
      switch(sub_menu) {
        case 0:
          lcd.print(">Chords");
          lcd.setCursor(0, 1);
          lcd.print(" Songs");
          break;
        case 1:
          lcd.print(">La Major");
          lcd.setCursor(0, 1);
          lcd.print(" Do Major");
          break;
        case 2:
          lcd.print(">Do Major");
          lcd.setCursor(0, 1);
          lcd.print(" Re Major");
          break;
        case 3:
          lcd.print(">Re Major");
          lcd.setCursor(0, 1);
          lcd.print(" Mi Major");
          break;
        case 4:
          lcd.print(">Mi Major");
          lcd.setCursor(0, 1);
          lcd.print(" Sol Major");
          break;
        case 5:
          lcd.print(">Sol Major");
          lcd.setCursor(0, 1);
          lcd.print(" La Minor");
          break;
        case 6:
          lcd.print(">La Minor");
          lcd.setCursor(0, 1);
          lcd.print(" Si Minor");
          break;
        case 7:
          lcd.print(">Si Minor");
          lcd.setCursor(0, 1);
          lcd.print(" Do Minor");
          break;
        case 8:
          lcd.print(">Do Minor");
          lcd.setCursor(0, 1);
          lcd.print(" Re Minor");
          break;
        case 9:
          lcd.print(">Re Minor");
          lcd.setCursor(0, 1);
          lcd.print(" Mi Minor");
          break;
        case 10:
          lcd.print(">Mi Minor");
          lcd.setCursor(0, 1);
          lcd.print(" Sol Minor");
          break;
        case 11:
          lcd.print(" Mi Minor");
          lcd.setCursor(0, 1);
          lcd.print(">Sol Minor");
          break;
      }
      break;
    case 3:
      lcd.clear();
      lcd.print(">Songs");
      lcd.setCursor(0, 1);
      lcd.print(" Demo");
      break;
    case 4:
      lcd.clear();
      lcd.print(" Songs");
      lcd.setCursor(0, 1);
      lcd.print(">Demo");
      break;
  }

}

void show_demo() {
  draw_snake();
  delay(200);
  col_by_col();
}

void draw_snake() {
  const char snake_leds[11][12][2] = {
    {
      {p1, p12}, {p1, p10}, {p1, p8}, {p1, p6}, {p1, p4}, {p1, p2},
      {p3, p2}, {p2, p4}, {p2, p6}, {p2, p8}, {p2, p10}, {p2, p12},
    },
    {
      {p3, p12}, {p3, p10}, {p3, p8}, {p3, p6}, {p3, p4}, {p4, p2},
      {p5, p2}, {p5, p4}, {p4, p6}, {p4, p8}, {p4, p10}, {p4, p12},
    },
    {
      {p5, p12}, {p5, p10}, {p5, p8}, {p5, p6}, {p6, p4}, {p6, p2},
      {p7, p2}, {p7, p4}, {p7, p6}, {p6, p8}, {p6, p10}, {p6, p12},
    },
    {
      {p7, p12}, {p7, p10}, {p7, p8}, {p8, p6}, {p8, p4}, {p8, p2},
      {p9, p2}, {p9, p4}, {p9, p6}, {p9, p8}, {p8, p10}, {p8, p12},
    },
    {
      {p9, p12}, {p9, p10}, {p10, p8}, {p10, p6}, {p10, p4}, {p10, p2},
      {p11, p2}, {p11, p4}, {p11, p6}, {p11, p8}, {p11, p10}, {p10, p12},
    },
    {
      {p11, p12}, {p12, p10}, {p12, p8}, {p12, p6}, {p12, p4}, {p12, p2},
      {p2, p1}, {p1, p3}, {p1, p5}, {p1, p7}, {p1, p9}, {p1, p11},
    },
    {
      {p2, p11}, {p2, p9}, {p2, p7}, {p2, p5}, {p2, p3}, {p3, p1},
      {p4, p1}, {p4, p3}, {p3, p5}, {p3, p7}, {p3, p9}, {p3, p11},
    },
    {
      {p4, p11}, {p4, p9}, {p4, p7}, {p4, p5}, {p5, p3}, {p5, p1},
      {p6, p1}, {p6, p3}, {p6, p5}, {p5, p7}, {p5, p9}, {p5, p11},
    },
    {
      {p6, p11}, {p6, p9}, {p6, p7}, {p7, p5}, {p7, p3}, {p7, p1},
      {p8, p1}, {p8, p3}, {p8, p5}, {p8, p7}, {p7, p9}, {p7, p11},
    },
    {
      {p8, p11}, {p8, p9}, {p9, p7}, {p9, p5}, {p9, p3}, {p9, p1},
      {p10, p1}, {p10, p3}, {p10, p5}, {p10, p7}, {p10, p9}, {p9, p11},
    },
    {
      {p10, p11}, {p11, p9}, {p11, p7}, {p11, p5}, {p11, p3}, {p11, p1},
      {p12, p1}, {p12, p3}, {p12, p5}, {p12, p7}, {p12, p9}, {p12, p11},
    }
  };

  char snake[SNAKE_LENGTH + 1][2] = {NULL};

  for (char i = 0; i < 11; i++) {
    for (char j = 0; j < 12; j++) {
      for(char k = 1; k < SNAKE_LENGTH; k++) {
        snake[k - 1][0] = snake[k][0];
        snake[k - 1][1] = snake[k][1];
      }
      
      snake[SNAKE_LENGTH - 1][0] = snake_leds[i][j][0];
      snake[SNAKE_LENGTH - 1][1] = snake_leds[i][j][1];

      print_snake(snake);
    }
  }

  for (char i = 0; i < SNAKE_LENGTH; i++) {
    for (char j = 1; j < SNAKE_LENGTH; j++) {
      snake[j - 1][0] = snake[j][0];
      snake[j - 1][1] = snake[j][1];
    }

    snake[SNAKE_LENGTH - 1][0] = NULL;
    snake[SNAKE_LENGTH - 1][1] = NULL;

    print_snake(snake);
  }
}

void print_snake(char snake[SNAKE_LENGTH][2]) {
  for(char t = 0; t < 80; t++){
    for(char i = 0; i < SNAKE_LENGTH; i++){
      if(snake[i][0] != NULL){
        init_leds();
        light(snake[i]);
      }
    }
  }
  init_leds();
}

void col_by_col() {
  const char snake_leds[11][12][2] = {
    {
      {p1, p12}, {p1, p10}, {p1, p8}, {p1, p6}, {p1, p4}, {p1, p2},
      {p3, p2}, {p2, p4}, {p2, p6}, {p2, p8}, {p2, p10}, {p2, p12},
    },
    {
      {p3, p12}, {p3, p10}, {p3, p8}, {p3, p6}, {p3, p4}, {p4, p2},
      {p5, p2}, {p5, p4}, {p4, p6}, {p4, p8}, {p4, p10}, {p4, p12},
    },
    {
      {p5, p12}, {p5, p10}, {p5, p8}, {p5, p6}, {p6, p4}, {p6, p2},
      {p7, p2}, {p7, p4}, {p7, p6}, {p6, p8}, {p6, p10}, {p6, p12},
    },
    {
      {p7, p12}, {p7, p10}, {p7, p8}, {p8, p6}, {p8, p4}, {p8, p2},
      {p9, p2}, {p9, p4}, {p9, p6}, {p9, p8}, {p8, p10}, {p8, p12},
    },
    {
      {p9, p12}, {p9, p10}, {p10, p8}, {p10, p6}, {p10, p4}, {p10, p2},
      {p11, p2}, {p11, p4}, {p11, p6}, {p11, p8}, {p11, p10}, {p10, p12},
    },
    {
      {p11, p12}, {p12, p10}, {p12, p8}, {p12, p6}, {p12, p4}, {p12, p2},
      {p2, p1}, {p1, p3}, {p1, p5}, {p1, p7}, {p1, p9}, {p1, p11},
    },
    {
      {p2, p11}, {p2, p9}, {p2, p7}, {p2, p5}, {p2, p3}, {p3, p1},
      {p4, p1}, {p4, p3}, {p3, p5}, {p3, p7}, {p3, p9}, {p3, p11},
    },
    {
      {p4, p11}, {p4, p9}, {p4, p7}, {p4, p5}, {p5, p3}, {p5, p1},
      {p6, p1}, {p6, p3}, {p6, p5}, {p5, p7}, {p5, p9}, {p5, p11},
    },
    {
      {p6, p11}, {p6, p9}, {p6, p7}, {p7, p5}, {p7, p3}, {p7, p1},
      {p8, p1}, {p8, p3}, {p8, p5}, {p8, p7}, {p7, p9}, {p7, p11},
    },
    {
      {p8, p11}, {p8, p9}, {p9, p7}, {p9, p5}, {p9, p3}, {p9, p1},
      {p10, p1}, {p10, p3}, {p10, p5}, {p10, p7}, {p10, p9}, {p9, p11},
    },
    {
      {p10, p11}, {p11, p9}, {p11, p7}, {p11, p5}, {p11, p3}, {p11, p1},
      {p12, p1}, {p12, p3}, {p12, p5}, {p12, p7}, {p12, p9}, {p12, p11},
    }
  };

  for (char i = 10; i >= 0; i--) {
    for (byte t = 0; t < 200; t++) {
      for (char j = 11; j > 5; j--) {
        init_leds();
        light(snake_leds[i][j]);
      }
    }
    init_leds();

    for (byte t = 0; t < 200; t++) {
      for (char j = 5; j >= 0; j--) {
        init_leds();
        light(snake_leds[i][j]);
      }
    }
    init_leds();
  }
}

void init_leds() {
  pinMode(p1, INPUT);
  pinMode(p2, INPUT);
  pinMode(p3, INPUT);
  pinMode(p4, INPUT);
  pinMode(p5, INPUT);
  pinMode(p6, INPUT);
  pinMode(p7, INPUT);
  pinMode(p8, INPUT);
  pinMode(p9, INPUT);
  pinMode(p10, INPUT);
  pinMode(p11, INPUT);
  pinMode(p12, INPUT);
}

void light(char pins[2]){
  pinMode(pins[0], OUTPUT);
  digitalWrite(pins[0], HIGH);

  pinMode(pins[1], OUTPUT);
  digitalWrite(pins[1], LOW);
}

void show_songs() {
  lcd.clear();
  lcd.print("  Coming soon");
  delay(2000);
}

void show_action() {
  switch(main_menu) {
    case 1: // notes
      switch(sub_menu) {
        case 1: note_Do(); break;
        case 2: note_DoD(); break;
        case 3: note_Re(); break;
        case 4: note_ReD(); break;
        case 5: note_Mi(); break;
        case 6: note_Fa(); break;
        case 7: note_FaD(); break;
        case 8: note_Sol(); break;
        case 9: note_SolD(); break;
        case 10: note_La(); break;
        case 11: note_LaD(); break;
        case 12: note_Si(); break;
      }
      break;
    case 2: // chords
      switch(sub_menu) {
        case 1: chord_La(); break;
        case 2: chord_Do(); break;
        case 3: chord_Re(); break;
        case 4: chord_Mi(); break;
        case 5: chord_Sol(); break;
        case 6: chord_LaM(); break;
        case 7: chord_SiM(); break;
        case 8: chord_DoM(); break;
        case 9: chord_ReM(); break;
        case 10: chord_MiM(); break;
        case 11: chord_SolM(); break;
      }
      break;
  }
}

// Notes
void note_Do() {
  char Do[11][2] = {      // C
    {p10, p2},
    {p11, p1},
    {p5, p4},
    {p6, p3},
    {p12, p6},
    {p6, p8},
    {p8, p7},
    {p2, p10},
    {p3, p9},
    {p9, p12},
    {p10, p11}
  };

  for (char i = 0; i < 11; i++) {
    init_leds();
    light(Do[i]);
  }
}
void note_DoD() {
  char DoD[9][2] = {      // Cs
    {p11, p2},
    {p6, p4},
    {p7, p3},
    {p1, p5},
    {p7, p8},
    {p9, p7},
    {p3, p10},
    {p4, p9},
    {p10, p12}
  };

  for (char i = 0; i < 9; i++) {
    init_leds();
    light(DoD[i]);
  }
}
void note_Re() {
  char Re[10][2] = {      // D
    {p12, p2},
    {p7, p4},
    {p8, p3},
    {p1, p6},
    {p2, p5},
    {p9, p8},
    {p10, p7},
    {p4, p10},
    {p5, p9},
    {p11, p12}
  };

  for (char i = 0; i < 10; i++) {
    init_leds();
    light(Re[i]);
  }
}
void note_ReD() {
  char ReD[10][2] = {
    {p2, p1},
    {p8, p4},
    {p9, p3},
    {p2, p6},
    {p3, p5},
    {p10, p8},
    {p11, p7},
    {p5, p10},
    {p6, p9},
    {p1, p11}
  };

  for (char i = 0; i < 10; i++) {
    init_leds();
    light(ReD[i]);
  }
}
void note_Mi() {
  char Mi[11][2] = {
    {p1, p2},
    {p3, p1},
    {p9, p4},
    {p10, p3},
    {p3, p6},
    {p4, p5},
    {p11, p8},
    {p6, p10},
    {p7, p9},
    {p1, p12},
    {p2, p11}
  };

  for (char i = 0; i < 11; i++) {
    init_leds();
    light(Mi[i]);
  }
}
void note_Fa() {
  char Fa[11][2] = {
    {p3, p2},
    {p4, p1},
    {p10, p4},
    {p11, p3},
    {p4, p6},
    {p6, p5},
    {p12, p8},
    {p7, p10},
    {p8, p9},
    {p2, p12},
    {p3, p11}
  };

  for (char i = 0; i < 11; i++) {
    init_leds();
    light(Fa[i]);
  }
}
void note_FaD() {
  char FaD[10][2] = {
    {p4, p2},
    {p5, p1},
    {p11, p4},
    {p5, p6},
    {p7, p5},
    {p1, p7},
    {p8, p10},
    {p10, p9},
    {p3, p12},
    {p4, p11}
  };

  for (char i = 0; i < 10; i++) {
    init_leds();
    light(FaD[i]);
  }
}
void note_Sol() {
  char Sol[11][2] = {
    {p5, p2},
    {p6, p1},
    {p12, p4},
    {p7, p6},
    {p8, p5},
    {p1, p8},
    {p2, p7},
    {p9, p10},
    {p11, p9},
    {p4, p12},
    {p5, p11}
  };

  for (char i = 0; i < 11; i++) {
    init_leds();
    light(Sol[i]);
  }
}
void note_SolD() {
  char SolD[10][2] = {
    {p6, p2},
    {p7, p1},
    {p1, p3},
    {p8, p6},
    {p9, p5},
    {p2, p8},
    {p3, p7},
    {p11, p10},
    {p5, p12},
    {p6, p11}
  };

  for (char i = 0; i < 10; i++) {
    init_leds();
    light(SolD[i]);
  }
}
void note_La() {
  char La[11][2] = {
    {p7, p2},
    {p8, p1},
    {p1, p4},
    {p2, p3},
    {p9, p6},
    {p10, p5},
    {p3, p8},
    {p4, p7},
    {p12, p10},
    {p6, p12},
    {p7, p11}
  };

  for (char i = 0; i < 11; i++) {
    init_leds();
    light(La[i]);
  }
}
void note_LaD() {
  char LaD[11][2] = {
    {p8, p2},
    {p9, p1},
    {p2, p4},
    {p4, p3},
    {p10, p6},
    {p11, p5},
    {p4, p8},
    {p5, p7},
    {p1, p9},
    {p7, p12},
    {p8, p11}
  };

  for (char i = 0; i < 11; i++) {
    init_leds();
    light(LaD[i]);
  }
}
void note_Si() {
  char Si[11][2] = {
    {p9, p2},
    {p10, p1},
    {p3, p4},
    {p5, p3},
    {p11, p6},
    {p5, p8},
    {p6, p7},
    {p1, p10},
    {p2, p9},
    {p8, p12},
    {p9, p11}
  };

  for (char i = 0; i < 11; i++) {
    init_leds();
    light(Si[i]);
  }
}

// Chords
void chord_La() {
  const uint8_t La[13][2] = {    // A
    {p1, p12},
    {p1, p10},
    {p1, p8},
    {p1, p6},
    {p1, p4},
    {p3, p10},
    {p3, p8},
    {p3, p6},
    {p12, p11},
    {p12, p9},
    {p12, p7},
    {p12, p5},
    {p12, p3}
  };

  for (uint8_t j = 0; j < 13; j++) {
    init_leds();
    light(La[j]);
  }
}
void chord_Do() {
  const uint8_t Do[13][2] = {    // C
    {p1, p12},
    {p1, p10},
    {p1, p8},
    {p1, p6},
    {p1, p4},
    {p2, p10},
    {p3, p6},
    {p5, p4},
    {p12, p11},
    {p12, p9},
    {p12, p7},
    {p12, p5},
    {p12, p3}
  };

  for (uint8_t j = 0; j < 13; j++) {
    init_leds();
    light(Do[j]);
  }
}
void chord_Re() {
  const uint8_t Re[11][2] = {    // D
    {p1, p12},
    {p1, p10},
    {p1, p8},
    {p1, p6},
    {p3, p12},
    {p3, p8},
    {p4, p10},
    {p12, p11},
    {p12, p9},
    {p12, p7},
    {p12, p5}
  };

  for (uint8_t j = 0; j < 11; j++) {
    init_leds();
    light(Re[j]);
  }
}
void chord_Mi() {
  const uint8_t Mi[15][2] = {    // E
    {p1, p12},
    {p1, p10},
    {p1, p8},
    {p1, p6},
    {p1, p4},
    {p1, p2},
    {p2, p8},
    {p3, p6},
    {p3, p4},
    {p12, p11},
    {p12, p9},
    {p12, p7},
    {p12, p5},
    {p12, p3},
    {p12, p1}
  };

  for (uint8_t j = 0; j < 15; j++) {
    init_leds();
    light(Mi[j]);
  }
}
void chord_Sol() {
  const uint8_t Sol[15][2] = {   // G
    {p1, p12},
    {p1, p10},
    {p1, p8},
    {p1, p6},
    {p1, p4},
    {p1, p2},
    {p3, p4},
    {p4, p12},
    {p5, p2},
    {p12, p11},
    {p12, p9},
    {p12, p7},
    {p12, p5},
    {p12, p3},
    {p12, p1}
  };

  for (uint8_t j = 0; j < 15; j++) {
    init_leds();
    light(Sol[j]);
  }
}
void chord_LaM() {
  const uint8_t LaM[13][2] = {   // Am
    {p1, p12},
    {p1, p10},
    {p1, p8},
    {p1, p6},
    {p1, p4},
    {p2, p10},
    {p3, p8},
    {p3, p6},
    {p12, p11},
    {p12, p9},
    {p12, p7},
    {p12, p5},
    {p12, p3}
  };

  for (uint8_t j = 0; j < 13; j++) {
    init_leds();
    light(LaM[j]);
  }
}
void chord_SiM() {
  const uint8_t SiM[18][2] = {   // Bm
    {p1, p12},
    {p1, p10},
    {p1, p8},
    {p1, p6},
    {p1, p4},
    {p3, p12},
    {p3, p10},
    {p3, p8},
    {p3, p6},
    {p3, p4},
    {p4, p10},
    {p5, p8},
    {p5, p6},
    {p12, p11},
    {p12, p9},
    {p12, p7},
    {p12, p5},
    {p12, p3}
  };

  for (uint8_t j = 0; j < 18; j++) {
    init_leds();
    light(SiM[j]);
  }
}
void chord_DoM() {
  const uint8_t DoM[18][2] = {   // Cm
    {p1, p12},
    {p1, p10},
    {p1, p8},
    {p1, p6},
    {p1, p4},
    {p4, p12},
    {p4, p10},
    {p4, p8},
    {p4, p6},
    {p5, p4},
    {p5, p10},
    {p6, p8},
    {p7, p6},
    {p12, p11},
    {p12, p9},
    {p12, p7},
    {p12, p5},
    {p12, p3}
  };

  for (uint8_t j = 0; j < 18; j++) {
    init_leds();
    light(DoM[j]);
  }
}
void chord_ReM() {
  const uint8_t ReM[11][2] = {   // Dm
    {p1, p12},
    {p1, p10},
    {p1, p8},
    {p1, p6},
    {p2, p12},
    {p3, p8},
    {p4, p10},
    {p12, p11},
    {p12, p9},
    {p12, p7},
    {p12, p5}
  };
  
  for (uint8_t j = 0; j < 11; j++) {
    init_leds();
    light(ReM[j]);
  }
}
void chord_MiM() {
  const uint8_t MiM[14][2] = {   // Em
    {p1, p12},
    {p1, p10},
    {p1, p8},
    {p1, p6},
    {p1, p4},
    {p1, p2},
    {p3, p6},
    {p3, p4},
    {p12, p11},
    {p12, p9},
    {p12, p7},
    {p12, p5},
    {p12, p3},
    {p12, p1}
  };

  for (uint8_t j = 0; j < 14; j++) {
    init_leds();
    light(MiM[j]);
  }
}
void chord_SolM() {
  const uint8_t SolM[20][2] = {  // Gm
    {p1, p12},
    {p1, p10},
    {p1, p8},
    {p1, p6},
    {p1, p4},
    {p1, p2},
    {p4, p12},
    {p4, p10},
    {p4, p8},
    {p4, p6},
    {p5, p4},
    {p5, p2},
    {p7, p6},
    {p7, p4},
    {p12, p11},
    {p12, p9},
    {p12, p7},
    {p12, p5},
    {p12, p3},
    {p12, p1}
  };

  for (uint8_t j = 0; j < 20; j++) {
    init_leds();
    light(SolM[j]);
  }

}

void loop() {
  // put your main code here, to run repeatedly:
}

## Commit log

2021-03-23 Added guitar project files (pcb, electric schema etc)
    [guitar.csv, guitar.sch, guitar_first.kicad_pcb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]
2021-03-23 Added Gerber and Drill files
    [guitar_first-B_Cu.gbr, guitar_first-B_Mask.gbr, guitar_first-B_SilkS.gbr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]
2021-04-21 Fixed pin numbering of port expander
    [guitar_second-B_Cu.gbr, guitar_second-B_Mask.gbr, guitar_second-B_SilkS.gbr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]
